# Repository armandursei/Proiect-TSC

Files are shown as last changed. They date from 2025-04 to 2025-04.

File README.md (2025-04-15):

# OpenBook e-Reader 
EBook_1

## Bill of Materials (BOM)

| Nume | Componenta | Link Cumpărare | Datasheet |
|---|---|---|---|
| Condensator C0402 | CC0402MRX5R5BB106 | [Link](https://ro.mouser.com/ProductDetail/YAGEO/CC0402MRX5R5BB106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) | [Datasheet](https://ro.mouser.com/datasheet/2/447/upy_gphc_x5r_4v_to_50v-3461255.pdf) |
| C10_SUPERCAP | CPH3225A | [Link](https://www.digikey.ro/en/products/detail/seiko-instruments/CPH3225A/8692444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) | [Datasheet](https://mm.digikey.com/Volume0/opasdata/d220001/medias/docus/6537/rev05-CPHCPM.pdf) |
| C3 TANT  | F910J107MBAAJ6 | [Link](https://ro.mouser.com/ProductDetail/KYOCERA-AVX/F910J107MBAAJ6?qs=PqoDHHvF649LraCA%2FjeGXg%3D%3D) | [Datasheet](https://ro.mouser.com/datasheet/2/40/F91_AJ6-3162641.pdf) |
| CHG_LED  | KP-1608SURCK | [Link](https://www.arrow.com/en/products/kp-1608surck/kingbright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) | [Datasheet](https://www.snapeda.com/parts/KP-1608SURCK/Kingbright/datasheet/) |
| D1 | USBLC6-2SC6Y | [Link](https://www.digikey.ro/en/products/detail/stmicroelectronics/USBLC6-2SC6Y/2756523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) | [Datasheet](https://componentsearchengine.com/Datasheets/1/USBLC6-2SC6Y.pdf) |
| D2, D7 | SD0805S020S1R0 | [Link](https://www.verical.com/pd/kyocera-avx-components-corporation-rectifier-SD0805S020S1R0-10867582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) | [Datasheet](https://www.digikey.ph/en/products/detail/kyocera-avx/SD0805S020S1R0/3749517) |
| D3, D4,D5 | MBR0530 | [Link](https://www.digikey.ro/en/products/detail/smc-diode-solutions/MBR0530/16692306) | [Datasheet](https://www.onsemi.com/pdf/datasheet/mbr0530-d.pdf) |
| D6, D8, D9, D10, D11, D12  | PGB1010603MR | [Link](https://www.digikey.ro/en/products/detail/littelfuse-inc/PGB1010603MR/715755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) | [Datasheet](https://www.snapeda.com/parts/PGB1010603MR/Littelfuse%20Inc./datasheet/) |
| IC1  | BD5229G-TR | [Link](https://www.digikey.ro/en/products/detail/rohm-semiconductor/BD5229G-TR/3663792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) | [Datasheet](https://datasheet.datasheetarchive.com/originals/distributors/Datasheets_SAMA/f2b9741ef86007909f138d561a359946.pdf) |
| IC4  | XC6220A331MR-G | [Link](https://www.digikey.ro/en/products/detail/torex-semiconductor-ltd/XC6220A331MR-G/21780806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) | [Datasheet](https://product.torexsemi.com/system/files/series/xc6220.pdf) |
| J1  | FH34SRJ-24S-0.5SH(99) | [Link](https://www.digikey.ro/en/products/detail/hirose-electric-co-ltd/FH34SRJ-24S-0.5SH(99)/5156248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) | [Datasheet](https://www.hirose.com/en/product/document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) |
| J2  | USB4110-GF-A | [Link](https://ro.mouser.com/ProductDetail/GCT/USB4110-GF-A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.) | [Datasheet](https://gct.co/files/drawings/usb4110.pdf) |
| J3 | SM04B-SRSS-TB | [Link](https://ro.mouser.com/ProductDetail/JST-Commercial/SM04B-SRSS-TBLFSN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) | [Datasheet](https://www.snapeda.com/parts/SM04B-SRSS-TB(LF)(SN)/JST%20Sales/datasheet/) |
| J4 | 112A-TAAR-R03 ATTEND | [Link](https://www.digikey.ro/en/products/detail/attend-technology/112A-TAAR-R03/17633923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) | [Datasheet](https://www.attend.com.tw/data/download/file/112A-TAAR-R03.pdf) |
| L1  | 744043680 | [Link](https://www.chip1stop.com/USA/en/products/Wurth-Electronics/744043680/WURT*0001522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) | [Datasheet](https://download.siliconexpert.com/pdfs/2018/1/3/16/30/56/604/weg_/manual/401950550574837744043680.pdf) |
| PFMF.050.1 | B72520T0350K062 | [Link](https://ro.mouser.com/ProductDetail/EPCOS-TDK/B72520T0350K062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) | [Datasheet](https://datasheet.datasheetarchive.com/originals/distributors/Datasheets_SAMA/81dc50a8c35dfdf39bcf4cbe36cdf37d.pdf) |
| Q1, Q2 | DMG2305UX-7 | [Link](https://www.digikey.ro/en/products/detail/diodes-incorporated/DMG2305UX-7/4340666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) | [Datasheet](https://www.diodes.com//assets/Datasheets/DMG2305UX.pdf) |
| Q3  | Si1308EDL-T1-GE3 | [Link](https://www.digikey.ro/ro/products/detail/vishay-siliconix/SI1308EDL-T1-GE3/4876435) | [Datasheet](https://componentsearchengine.com/Datasheets/1/SI1308EDL-T1-GE3.pdf) |
| Rezistenta 0402 | RC0402FR-07100KL | [Link](https://ro.mouser.com/ProductDetail/YAGEO/RC0402FR-07100KL?qs=mnq%2FyloZIXzTlUn7JAHSWg%3D%3D) | [Datasheet](https://www.yageo.com/upload/media/product/products/datasheet/rchip/PYu-RC_Group_51_RoHS_L_12.pdf) |
| RESET_BUTTON, CHANGE_BUTTON, BOOT_BUTTON | EVQPUJ02K | [Link](https://ro.mouser.com/ProductDetail/Panasonic/EVQ-PUJ02K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) | [Datasheet](https://www.alldatasheet.com/datasheet-pdf/view/537835/PANASONIC/EVQPUJ02K.html) |
| SENSOR2  | BME680 | [Link](https://www.digikey.ro/en/products/detail/bosch-sensortec/BME680/7401317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) | [Datasheet](https://www.snapeda.com/parts/BME680/Bosch%20Sensortec/datasheet/) |
| SJ1 | Solid Jumpers | [Link](https://ro.mouser.com/ProductDetail/Keystone-Electronics/5104?qs=SKxV22VtNmeKXYob26ai6Q%3D%3D) | [Datasheet](https://www.digikey.ro/en/htmldatasheets/production/1809569/0/0/1/jumpers) |
| U1 | W25Q512JVEIQ | [Link](https://www.digikey.ro/en/products/detail/winbond-electronics/W25Q512JVEIQ/10244706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) | [Datasheet](https://www.snapeda.com/parts/W25Q512JVEIQ/Winbond%20Electronics/datasheet/) |
| U2  | ESP32-C6-WROOM-1-N8 | [Link](https://www.digikey.ro/en/products/detail/espressif-systems/ESP32-C6-WROOM-1-N8/17728866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) | [Datasheet](https://www.snapeda.com/parts/ESP32-C6-WROOM-1-N8/Espressif%20Systems/datasheet/) |
| U3  | DS3231SN# | [Link](https://www.digikey.ro/en/products/detail/analog-devices-inc-maxim-integrated/DS3231SN/1197576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) | [Datasheet](https://www.snapeda.com/parts/DS3231SN%23/Analog%20Devices/datasheet/) |
| U4  | MAX17048G+T10 | [Link](https://www.digikey.ro/en/products/detail/analog-devices-inc-maxim-integrated/MAX17048G-T10/3758921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) | [Datasheet](https://www.snapeda.com/parts/MAX17048G+T10/Analog%20Devices/datasheet/) |
| U5  | MCP73831 | [Link](https://ro.mouser.com/ProductDetail/Microchip-Technology/MCP73831T-2ACI-OT?qs=yUQqVecv4qvbBQBGbHx0Mw%3D%3D) | [Datasheet](https://datasheet.datasheetarchive.com/originals/distributors/Datasheets-DGA15/727147.pdf) |

## Diagrama Bloc
svgviewer-png-output

# Descriere Hardware
PCB_2

## Introducere
OpenBook este un dispozitiv e-book reader open-source și accesibil, conceput pentru a oferi o experiență de lectură eficientă și cu consum redus de energie. Proiectarea hardware urmărește obținerea unei soluții robuste, cu interconectări curate și o bună compatibilitate electromagnetică.
Dispozitivul este construit în jurul microcontroller-ului ESP32-C6, care oferă conectivitate Wi-Fi și Bluetooth Low Energy (BLE), o putere de procesare eficientă și suport extins pentru periferice.
## Microcontroller: ESP32-C6-WROOM-1-N8
- Procesor: RISC-V 32-bit, frecvență până la 160 MHz
- Memorie: 8MB Flash integrată + memorie externă SPI NOR Flash de 64 MB (W25Q512JVEIQ) pentru stocarea conținutului cărților electronice
- Interfețe utilizate:
  - SPI: conectat la display-ul e-paper și la memoria externă NOR Flash
  - I2C: pentru senzori externi (ex. senzor de mediu BME688) și RTC (DS3231SN)
  - UART: disponibil pentru debugging
  - GPIO: folosit pentru butoane de control, reset, și alte semnale de comandă pentru periferice
- Antena: Amplasată corect, conform cerințelor, spre exteriorul PCB-ului, cu decupare sub antenă pentru evitarea interferențelor.
## Module și componente principale
### Display e-Paper

Interfață: SPI

Control semnale: EPD_CS, EPD_RST, EPD_DC, EPD_BUSY

Display consum redus de energie, perfect pentru citire pe durată lungă.

### Memorie Externă

Model: W25Q512JVEIQ, 512Mbit NOR Flash

Interfață: SPI

Utilizare: stocare cărți electronice, fonturi, imagini etc.

### Senzor de mediu: BME688

Funcții: măsurare temperatură, presiune, umiditate și compuși organici volatili (VOC)

Interfață: I2C

Consum: extrem de redus.

### Modul RTC (Real Time Clock) — DS3231SN

Funcție: menține ora exactă, chiar și în absența alimentării principale

Interfață: I2C

Include funcționalitate de alarmă și ieșire SQW/INT.

### Baterie și circuit de încărcare

Controler încărcare: MCP73831

Indicator stare: LED 'CHG_LED'

Conector: USB-C pentru încărcare rapidă

Protecție la supratensiune și ESD.

### Sursă de alimentare și reglare tensiune

Regulator LDO: XC6220A331MR-G, 3.3V stabilizat

Condensatori de decuplare de 100nF

Trasee de alimentare rutate cu lățime de 0.3mm.

### Port de extindere Qwiic / Stemma QT

Pentru conectarea rapidă a senzorilor sau modulelor suplimentare prin I2C.

### Test pads marcate clar

Semnalele importante sunt disponibile pentru debugging și testare.

## Conectivitate și comunicare

| Componentă | Interfață cu MCU | Linii semnal |
|---|---|---|
| Display e-paper | SPI | MOSI, MISO, SCK, CS, DC, BUSY, RST |
| Memorie externă Flash | SPI | MOSI, MISO, SCK, CS |
| RTC | I2C | SDA, SCL |
| Senzor BME688 | I2C | SDA, SCL |
| Port extensie Qwiic | I2C | SDA, SCL |
| Charging Controller | USB | VBUS, GND, STAT LED |

## Management consum de energie
- Display-ul e-paper consumă energie doar la schimbarea imaginii.
- ESP32 poate intra în moduri de deep sleep pentru maximizarea autonomiei.
- RTC funcționează cu consum ultra scăzut și poate trezi MCU la intervale prestabilite.
- Alimentare stabilizată la 3.3V prin LDO cu ripple redus.
- Condensatori de filtrare atent poziționați pentru minimizarea zgomotului.
### Estimare consum tipic:

Stare dispozitiv	                Consum estimativ

Active Wi-Fi + e-paper update	    ~180-250 mA

Standby cu RTC activ	            ~10-20 µA

Deep Sleep	                      ~2.5 µA

## Considerații suplimentare
- PCB-ul este proiectat pe două straturi, cu plan de masă solid și via stitching pentru performanță EMC îmbunătățită.
- Sub antena ESP32 PCB-ul este decupat pentru a reduce interferențele radio.
- Toate componentele sunt SMD, capsulă 0402, cu excepția celor specificate diferit în schematic.
- Componentele sunt amplasate exclusiv pe layer-ul TOP pentru o producție mai facilă.
# Pin Mapping ESP32-C6
# OpenBook e-Reader — Atribuire pini ESP32-C6

| Componentă | Pin ESP32-C6 | Funcție | Motivare alegere |
|---|---|---|---|
| Display e-paper (SPI) | IO4 (MOSI) | MOSI | Pin dedicat SPI, viteză mare pentru trimitere date la display |
| | IO5 (MISO) | MISO | Comunicare bidirecțională SPI |
| | IO6 (SCK) | Clock SPI | Sincronizare transfer date |
| | IO7 | Chip Select | Activare selectivă display |
| | IO8 | Data/Command (DC)  | Comutare între date și comenzi |
| | IO9 | Reset Display (RST)| Reset hardware display |
| | IO10 | Busy Pin | Verificare stare display pentru sincronizare fără blocare |
| Memorie externă Flash (SPI)  | IO4 (MOSI) | MOSI | Partajare magistrală SPI cu display |
| | IO5 (MISO) | MISO | Partajare magistrală SPI cu display |
| | IO6 (SCK) | Clock SPI | Partajare magistrală SPI cu display |
| | IO11 | Chip Select Flash  | Separare comunicație SPI față de display |
| RTC DS3231SN (I2C) | IO18 | SDA | Linie de date I2C, partajată cu senzor BME688 |
| | IO19 | SCL | Clock I2C, partajat cu senzor BME688 |
| Senzor BME688 (I2C) | IO18 | SDA | Linie de date partajată cu RTC |
| | IO19 | SCL | Clock partajat cu RTC |
| Buton de Reset | EN | Reset | Pin nativ ESP32 pentru reset hardware |
| Buton de Boot/IO | IO0 | Boot | Intrare pentru modul de boot/flash firmware |
| Charging Status (LED) | IO13 | GPIO Output | Semnalizare vizuală stare încărcare |
| Test pad-uri Debug UART | IO16 | TXD0 | Linie de transmisie UART pentru debug |
| | IO17 | RXD0 | Linie de recepție UART pentru debug |

## Explicații detaliate
### Display e-paper

Am ales să folosim SPI, deoarece e-paper are nevoie de transferuri rapide de date pentru actualizări eficiente ale ecranului.

Pinul IO4 (MOSI) și IO6 (SCK) sunt convențional buni pentru SPI, oferind viteze mari de transfer.

Pinul de Chip Select (IO7) separă comunicarea față de memoria Flash externă, iar IO8 (DC) controlează modul de funcționare (date/comenzi).

IO9 (RST) asigură reset hardware pentru inițializarea display-ului.

IO10 (BUSY) permite MCU-ului să verifice dacă ecranul e-paper este ocupat, evitând astfel blocajele.

### Memorie externă Flash

Partajăm magistrala SPI cu display-ul pentru eficiență (reducere număr pini).

Am folosit Chip Select separat (IO11) pentru Flash, astfel încât ESP32 să poată comuta între display 
și memorie externă după nevoie.

### RTC și Senzor BME688

Folosim I2C comun pentru ambele componente pentru simplitate și economie de pini.

Linia SDA (IO18) și SCL (IO19) sunt partajate fără probleme, întrucât atât RTC-ul cât și senzorul BME688 au adrese I2C diferite.

### Circuit de încărcare baterie

Indicatorul de stare (STAT) este conectat la IO13, ca să putem afișa cu LED starea de încărcare.

### Butoane hardware

Butonul de reset este legat la EN, care este pinul nativ de reset al ESP32.

Butonul de boot este pe IO0, conform recomandărilor ESP32 pentru intrarea în modul de programare (flash firmware).

### Test pad-uri Debug

UART hardware ESP32-C6:
- TXD0 = IO16
- RXD0 = IO17

Astfel, putem face debugging rapid prin UART fără să ocupăm pini suplimentari pentru comunicație.

### Considerații adiționale

Toți pinii critici de alimentare sunt decuplați cu condensatori de 100nF montați aproape de pini.

Pinii folosiți pentru comunicații de mare viteză (SPI) sunt poziționați cu trasee scurte pentru a evita interferențele și cross-talk-ul.

Pinii de alimentare și date respectă specificațiile de lățime traseu: alimentare 0.3mm, date 0.15mm minim.

## Pașii de implementare, probleme întâmpinate și decizii de proiectare
### 1. Analiza cerințelor și planificarea
Am pornit de la specificațiile oferite de Arhitectul de Sistem, incluzând cerințele legate de rutare, dimensiuni, modul de amplasare a componentelor și normele EMC.
Am stabilit următoarele priorități:
- Miniaturizarea PCB-ului fără a compromite performanța RF.
- Asigurarea unei alimentări stabile și curate pentru toate modulele.
- Design modular, cu posibilitate de extensie prin conectorul Qwiic / Stemma QT.
### 2. Crearea schematicului electric
- Tool utilizat: Fusion
- Am inclus toate modulele cerute: ESP32-C6, RTC, senzor BME688, controller încărcare baterie, memorie externă NOR Flash, e-paper.
- Am adăugat protecție ESD pentru liniile sensibile (USB, SPI).
- Toate alimentările sunt filtrate cu condensatori de decuplare de 100nF, plasați cât mai aproape de pinii circuitelor integrate.
### 3. Layout PCB
Tool utilizat: Fusion

Amplasarea componentelor s-a realizat exclusiv pe layer-ul TOP, conform cerinței.

Am acordat o atenție deosebită următoarelor aspecte:
- Antena ESP32: amplasată la marginea plăcii, cu decupare sub antenă pentru a evita interferențele.
- Planuri de masă: am utilizat două straturi de plan de masă și aplicat via stitching intensiv, mai ales în zona ESP32 pentru integritate semnal și reducere EMI.
- Lățimi trasee: am respectat cerințele — alimentare 0.3mm, date min. 0.15mm.
- Test pad-uri: marcate clar pe silkscreen pentru facilitarea testării în faza de prototip și producție.

## Probleme întâmpinate:

- Conflict spațial în jurul modulului ESP32

- Modulul ESP32-C6 și componentele de alimentare și filtrare RF necesitau plasare compactă.

  Soluție: am rearanjat componentele pentru a evita utilizarea de vias pe traseele de alimentare critice, păstrând totodată trasee scurte pentru semnalele de mare viteză.

- Overlap parțial plan de masă și zona antenei

- Am detectat inițial o intersecție accidentală a planului de masă cu zona de sub antena ESP32.

  Decizie: am ajustat conturul planului de masă pentru a menține zona sub antenă complet liberă de cupru și trasee, astfel încât să reducem interferențele RF.

- Erori de clearance / distanță minimă între trasee

- În anumite zone dense (ex: header-ul display-ului e-paper), am acceptat un clearance minim redus, întrucât fabricația modernă permite aceste toleranțe fără probleme.

  Am verificat designul cu DRC (Design Rule Check) pentru a ne asigura că rămâne în limitele permise de procesul de fabricație.

- Trasee lungi SPI către e-paper

- Fiind vorba de un semnal de mare viteză, am minimizat lungimea traseelor SPI prin plasarea controlerului e-paper cât mai aproape de ESP32, fără a compromite layout-ul general.

### 4. Verificare design (Design Review)
Am verificat manual toate traseele critice de alimentare și comunicații.
Am verificat DRC și ERC (Electrical Rule Check) cu tool-ul primit.
### 5. Pregătire pentru producție
Am generat fișierele Gerber și BOM (Bill of Materials).
### 6. Integrare 3D și Ansamblu final
- Model 3D pentru display și baterie:
  Am creat modele 3D detaliate pentru display-ul e-paper și pentru bateria Li-Po, pentru a verifica potrivirea componentelor în ansamblu.

- Integrare în carcasa existentă: Carcasa dispozitivului a fost preexistentă, însă am verificat alinierea perfectă a PCB-ului, ecranului și conectorilor în cadrul carcasei.
Am ajustat poziționarea componentelor astfel încât:
  - Ecranul să fie corect centrat și bine susținut mecanic.
  - Accesul la portul USB-C pentru încărcare să fie facil.
  - Zonele pentru antenă să fie libere de obstacole mecanice, pentru optimizarea performanței RF.

- Ansamblul complet:
  Am realizat ansamblul final al dispozitivului, verificând:
  - Compatibilitatea tuturor componentelor între ele.
  - Posibilitatea de asamblare eficientă în producție de masă.
  - Rigiditatea mecanică și siguranța fixării componentelor critice.

- Verificare clearance și coliziuni:
  Am utilizat funcționalitățile software de verificare pentru a elimina orice potențiale coliziuni între PCB, display și carcasă.

Decizie:
Integrarea 3D ne-a ajutat să anticipăm și să prevenim probleme mecanice înainte de prototipare fizică, economisind timp și resurse.
## Observații suplimentare pentru
### 1. Design log și proces iterativ
Am menținut un jurnal de design pe parcursul întregului proiect pentru a urmări deciziile și iterațiile importante:
- Inițial: amplasare funcțională, fără optimizări mecanice.
- Revizia 1: optimizare rutare alimentare pentru a evita vias pe liniile de putere.
- Revizia 2: îmbunătățire layout antenă ESP32 conform cerințelor RF, eliminare completă cupru sub antenă.
- Revizia 3: verificări de clearance și marcaje test pad-uri adăugate.
- Final: integrare 3D și verificare ansamblu complet.

Fiecare modificare a fost documentată și validată cu peer-review înainte de trecerea la următoarea etapă, pentru a asigura trasabilitatea deciziilor tehnice.
### 2. Așezarea componentelor în carcasă
Am tratat cu maximă atenție integrarea PCB-ului în carcasă, pentru a preveni probleme de asamblare:
- Ecran e-paper: Poziționat central, cu suport mecanic prin carcasă, astfel încât să nu existe flexare excesivă a PCB-ului în timpul montajului.
- Conector USB-C: Verificat poziționarea precisă față de decupajul carcasei pentru a asigura conectivitate ușoară și fără tensiune mecanică asupra PCB-ului.
- Bateria: Amplasată astfel încât să fie bine susținută mecanic de carcasă și conectată fără forțări la conectorul de alimentare.
- Test pad-uri și acces pentru testare: Test pad-urile sunt plasate în zone accesibile chiar și după asamblarea mecanică parțială, pentru testare de producție și depanare rapidă.
### 3. Considerații pentru fabricație și asamblare
- Montaj exclusiv pe TOP layer — simplifică semnificativ procesul de asamblare SMT.
- Testabilitate: Am prevăzut acces facil la semnalele critice prin test pad-uri, inclusiv alimentare, date SPI/I2C și UART debug.
- Marcare clară a componentelor: Silkscreen detaliat pentru identificarea ușoară a componentelor în timpul asamblării și depanării.
- Gerber Files și BOM pregătite complet pentru producție.
### 4. Recomandări pentru viitor
- Se poate lua în considerare utilizarea unor conectori interni suplimentari pentru extensii hardware (de exemplu: card reader extern sau interfață audio).
- O viitoare iterație poate integra și un sistem de ancorare mecanică mai robust pentru baterie.
- Posibilitate de optimizare suplimentară a layout-ului pentru EMC, prin adăugarea de ferite pe liniile critice de alimentare.
## Concluzii
Prin acest proces, am obținut un design robust, pregătit pentru producție de masă, care respectă toate cerințele de design impuse:
- Optimizare RF pentru modulul ESP32.
- Fiabilitate electrică prin alimentare stabilizată și filtrată.
- Extensibilitate prin conectorul I2C dedicat.

Deciziile noastre de layout și compromisurile (acceptarea unor clearance minime, optimizarea pentru fabricație) au fost deliberate și validate atât prin analiza manuală, cât și prin verificări automate.
Pe lângă validarea electrică și de fabricație, proiectul a fost validat și la nivel mecanic prin integrarea completă în ansamblul 3D al dispozitivului.
Acest lucru asigură nu doar funcționarea corectă a circuitului, ci și faptul că produsul final va avea un aspect profesional și va fi ușor de asamblat în producția de masă.

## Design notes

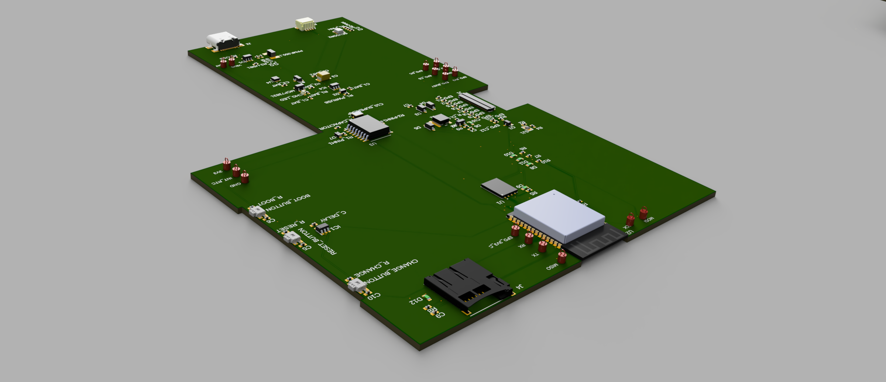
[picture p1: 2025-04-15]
Images/PCB_3.png

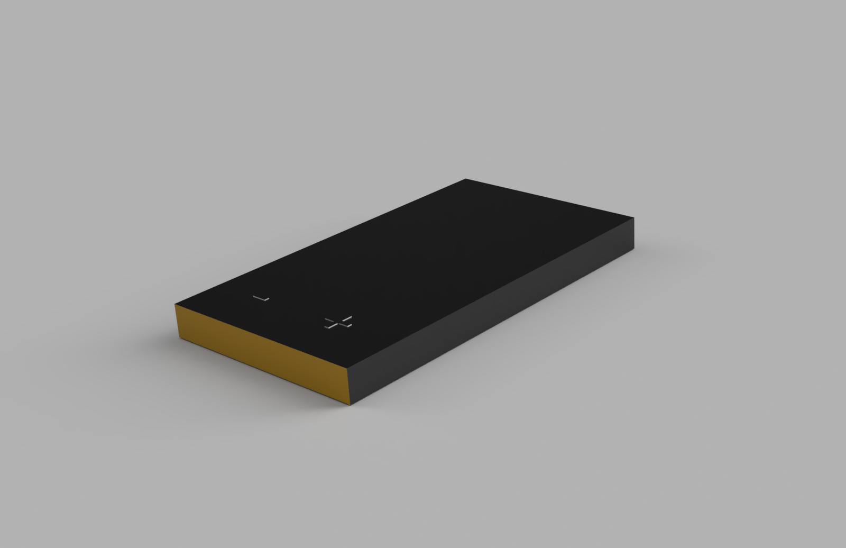
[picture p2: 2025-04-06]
Images/Battery.PNG

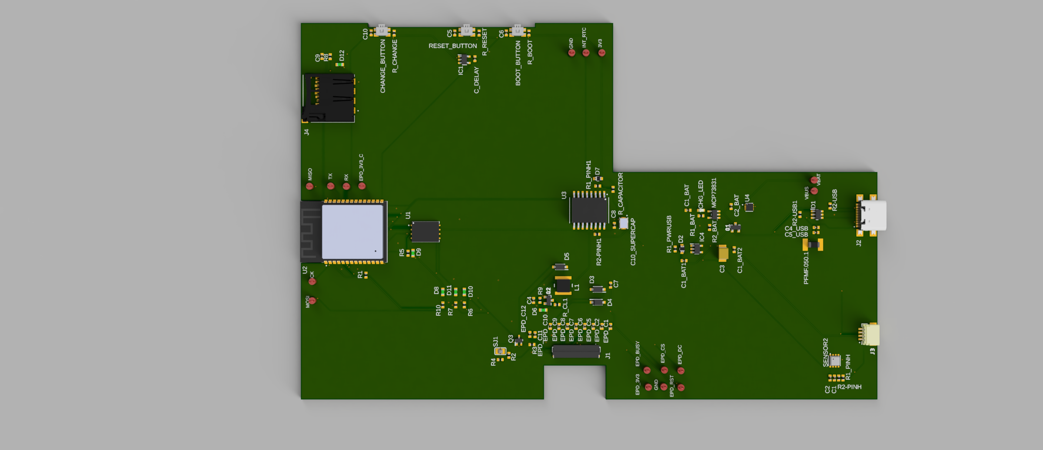
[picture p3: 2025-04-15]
Images/PCB_1.png

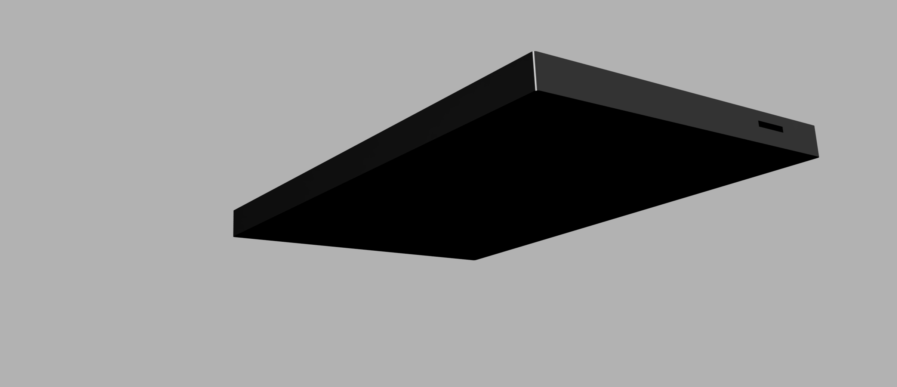
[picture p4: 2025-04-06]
Images/EBook_2.PNG

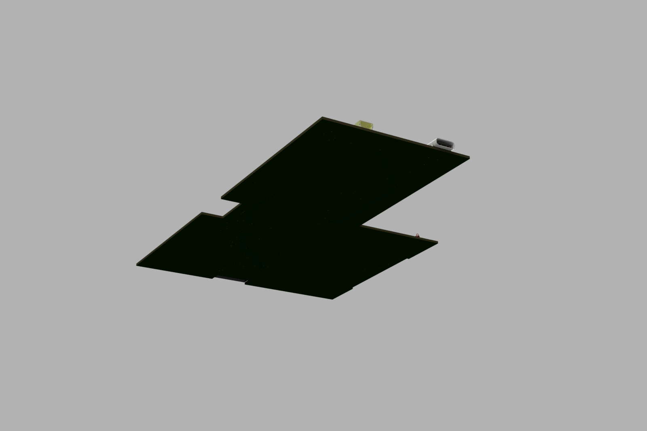
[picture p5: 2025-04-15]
Images/PCB_5.PNG

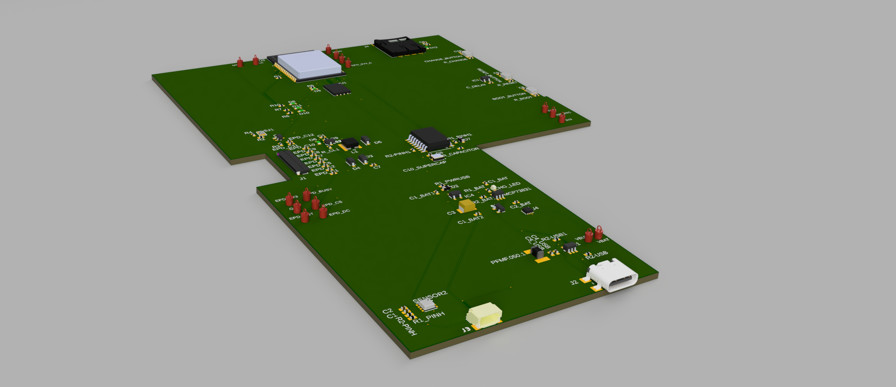
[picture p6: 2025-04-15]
Images/PCB_2.png

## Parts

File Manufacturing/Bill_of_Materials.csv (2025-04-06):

Qty | Value | Device | Package | Parts | Description | ARROW_PART_NUMBER | ARROW_PRICE-STOCK | AVAILABILITY | CENTROID_NOT_SPECIFIED | CHECK_PRICES | COPYRIGHT | DATASHEET | DESCRIPTION | DIGIKEY_DESCRIPTION | DIGIKEY_PART_NUMBER | HEIGHT | LEAD_FREE | MANUFACTURER_NAME | MANUFACTURER_PART_NUMBER | MF | MFR_NAME | MOUSER_PART_NUMBER | MOUSER_PRICE-STOCK | MOUSER_TESTING_PART_NUMBER | MOUSER_TESTING_PRICE-STOCK | MP | MPN | PACKAGE | POPULARITY | PREFIX | PRICE | PROD_ID | PURCHASE-URL | ROHS | SNAPEDA_LINK | SPICEPREFIX | TEMPERATURE_RANGE_HIGH | TEMPERATURE_RANGE_LOW | VALUE
1 |  | ADAFRUIT_LEDCHIP-LED0603 | ADAFRUIT_CHIP-LED0603 | CHG_LED | LED
1 |  | SJ | SJ | SJ1 | SMD solder JUMPER |  |  |  |  |  |  |  |  |  |  |  |  |  |  |  |  |  |  |  |  |  |  |  | 3
1 | 0.1uF/50V | ESP32_WROVER_EAGLE-LTSPICE_CC0402 | ESP32_WROVER_EAGLE-LTSPICE_C0402 | EPD_C5 | CAPACITOR, European symbol
1 | 0.47 | ESP32_WROVER_EAGLE-LTSPICE_RR0402 | ESP32_WROVER_EAGLE-LTSPICE_R0402 | R3 | RESISTOR, European symbol
1 | 100K | ESP32_WROVER_EAGLE-LTSPICE_RR0402 | ESP32_WROVER_EAGLE-LTSPICE_R0402 | R1_PWRUSB | RESISTOR, European symbol
8 | 100nF | ESP32_WROVER_EAGLE-LTSPICE_CC0402 | ESP32_WROVER_EAGLE-LTSPICE_C0402 | C1, C2, C4_USB, C6, C8, C9, C10, C_DELAY | CAPACITOR, European symbol
1 | 100uF TANT | RCL_CPOL-EUCT3528 | RCL_CT3528 | C3 | POLARIZED CAPACITOR, European symbol |  |  |  |  |  |  |  |  |  |  |  |  |  |  |  |  |  |  |  |  |  |  |  | 0 |  |  |  |  |  |  | C
16 | 10K | ESP32_WROVER_EAGLE-LTSPICE_RR0402 | ESP32_WROVER_EAGLE-LTSPICE_R0402 | R1, R1_PINH, R1_PINH1, R2-PINH, R2-PINH1, R4, R5, R6, R7, R8, R9, R10, R_BOOT, R_CHANGE, R_CL1, R_RESET | RESISTOR, European symbol
1 | 10uF | ESP32_WROVER_EAGLE-LTSPICE_CC0402 | ESP32_WROVER_EAGLE-LTSPICE_C0402 | C7 | CAPACITOR, European symbol
1 | 112A-TAAR-R03_ATTEND | 112A-TAAR-R03_ATTEND | 112ATAARR03ATTEND | J4 | Micro SD Card Socket, Push-Push Type, Top Mount, SMT, H=1.83mm, 10u |  |  |  |  |  |  |  | Micro SD Card Socket | Push-Push Type | Top Mount | SMT | H=1.83mm | 10u |  |  | 1.9mm |  | ATTEND | 112A-TAAR-R03 ATTEND
1 | 15 | ESP32_WROVER_EAGLE-LTSPICE_RR0402 | ESP32_WROVER_EAGLE-LTSPICE_R0402 | R_CAPACITOR | RESISTOR, European symbol
1 | 1uF | ESP32_WROVER_EAGLE-LTSPICE_CC0402 | ESP32_WROVER_EAGLE-LTSPICE_C0402 | C5 | CAPACITOR, European symbol
9 | 1uF/50V | ESP32_WROVER_EAGLE-LTSPICE_CC0402 | ESP32_WROVER_EAGLE-LTSPICE_C0402 | EPD_C1, EPD_C2, EPD_C6, EPD_C7, EPD_C8, EPD_C9, EPD_C10, EPD_C11, EPD_C12 | CAPACITOR, European symbol
1 | 2.2 | ESP32_WROVER_EAGLE-LTSPICE_RR0402 | ESP32_WROVER_EAGLE-LTSPICE_R0402 | R2 | RESISTOR, European symbol
1 | 200 | ESP32_WROVER_EAGLE-LTSPICE_RR0402 | ESP32_WROVER_EAGLE-LTSPICE_R0402 | R1_BAT | RESISTOR, European symbol
2 | 20V/4.2A/52mΩ/1.4W | ESP32_WROVER_SPARKFUN-DISCRETESEMI_MOSFET_PCH-DMG2305UX-7 | ESP32_WROVER_SPARKFUN-DISCRETESEMI_SOT23-3 | Q1, Q2 | P-channel MOSFETs |  |  |  |  |  |  |  |  |  |  |  |  |  |  |  |  |  |  |  |  |  |  |  |  |  |  | TRAN-14388 |  |  |  |  |  |  | 20V/4.2A/52mΩ/1.4W
1 | 2K | ESP32_WROVER_EAGLE-LTSPICE_RR0402 | ESP32_WROVER_EAGLE-LTSPICE_R0402 | R2_BAT | RESISTOR, European symbol
5 | 4.7uF | ESP32_WROVER_EAGLE-LTSPICE_CC0402 | ESP32_WROVER_EAGLE-LTSPICE_C0402 | C1_BAT, C1_BAT1, C1_BAT2, C2_BAT, C5_USB | CAPACITOR, European symbol
1 | 4.7uF/25V | ESP32_WROVER_EAGLE-LTSPICE_CC0402 | ESP32_WROVER_EAGLE-LTSPICE_C0402 | C4 | CAPACITOR, European symbol
2 | 5k1 | ESP32_WROVER_EAGLE-LTSPICE_RR0402 | ESP32_WROVER_EAGLE-LTSPICE_R0402 | R2-USB, R2-USB1 | RESISTOR, European symbol
1 | 68uH | 744043680IND_4828-WE-TPC_WRE | IND_4828-WE-TPC_WRE | L1 |  |  |  |  |  |  | Copyright (C) 2024 Ultra Librarian. All rights reserved. |  |  |  |  |  |  |  | 744043680 |  | Wurth Electronics
1 | BD5229G-TR | BD5229G-TR | SOT95P280X125-5N | IC1 | Voltage Detector with Adjustable Delay Time: CMOS processes are utilized to develop high precision, low current consumption CMOS reset ICs that allow arbitrary setting of the delay time. The extensive lineup includes both Nch Open Drain and CMOS output types in a wide range of detection voltages (from 2.3V to 6.0V, in 0.1V steps), enabling selection of the ideal solution based on customer requirements. In addition, the entire series is of course both lead-free and RoHS-compliant. |  |  |  |  |  |  |  | Voltage Detector with Adjustable Delay Time: CMOS processes are utilized to develop high precision | low current consumption CMOS reset ICs that allow arbitrary setting of the delay time. The extensive lineup includes both Nch Open Drain and CMOS output types in a wide range of detection voltages (from 2.3V to 6.0V | in 0.1V steps) | enabling selection of the ideal solution based on customer requirements. In addition | the entire series is of course both lead-free and RoHS-compliant. |  |  | 1.25mm |  | ROHM Semiconductor | BD5229G-TR |  |  | 755-BD5229G-TR | https://www.mouser.co.uk/ProductDetail/ROHM-Semiconductor/BD5229G-TR?qs=4kLU8WoGk0vvnhrrYwdszw%3D%3D
1 | BME688 | ESP32_WROVER_BME680_BME680 | ESP32_WROVER_BME680_PSON80P300X300X100-8N | SENSOR2 | Integrated Environmental Unit |  |  | Unavailable |  |  |  |  | Integrated Environmental Unit |  |  |  |  |  |  | Bosch Sensortec |  |  |  |  |  | BME680 |  | LGA-8 Bosch Tools |  |  | None
3 | BUTTON_CUSYOMV1 | BUTTON_CUSYOMV1 | MYBUTTON | BOOT_BUTTON, CHANGE_BUTTON, RESET_BUTTON
1 | CPH3225A | CPH3225A | CAPCP3225X100N | C10_SUPERCAP | Cap 0.011F 3.3V 1210 Flat Check availability |  |  | Not in stock |  | https://www.snapeda.com/parts/CPH3225A/Seiko+Instruments/view-part/?ref=eda |  |  | 11 mF (EDLC) Supercapacitor 3.3 V 1210 (3225 Metric) - - |  |  |  |  |  |  | Seiko Instruments |  |  |  |  |  | CPH3225A |  | 1210 Seiko |  |  | None |  | https://www.snapeda.com/api/url_track_click_mouser/?unipart_id=562593&manufacturer=Seiko Instruments&part_name=CPH3225A&search_term=None |  | https://www.snapeda.com/parts/CPH3225A/Seiko+Instruments/view-part/?ref=snap
1 | DS3231SN# | DS3231SN# | SOIC127P1032X265-16N | U3 | Real Time Clock Serial 16-Pin SOIC W T/R Check availability |  |  | In Stock |  | https://www.snapeda.com/parts/DS3231SN%23/Analog+Devices/view-part/?ref=eda |  |  | Extremely Accurate I²C-Integrated RTC/TCXO/Crystal |  |  |  |  |  |  | Analog Devices |  |  |  |  |  | DS3231SN# |  | SOIC-16 Maxim |  |  | None |  | https://www.snapeda.com/api/url_track_click_mouser/?unipart_id=99048&manufacturer=Analog Devices&part_name=DS3231SN#&search_term=None |  | https://www.snapeda.com/parts/DS3231SN%23/Analog+Devices/view-part/?ref=snap
1 | ESP32-C6-WROOM-1-N8 | ESP32-C6-WROOM-1-N8 | XCVR_ESP32-C6-WROOM-1-N8 | U2 | Check availability |  |  | In Stock |  | https://www.snapeda.com/parts/ESP32-C6-WROOM-1-N8/Espressif+Systems/view-part/?ref=eda |  |  | Multiprotocol Modules ESP32-C6 module | Wi-Fi 6 in 2.4 GHz band | Bluetooth 5 | Zigbee 3.0 and Thread. ESP34-WROOM Compatible - ENGINEERING SAMPLE |  |  |  |  |  |  | Espressif Systems |  |  |  |  |  | ESP32-C6-WROOM-1-N8 |  | None |  |  | None |  |  |  | https://www.snapeda.com/parts/ESP32-C6-WROOM-1-N8/Espressif+Systems/view-part/?ref=snap
1 | ESP32C6_VARISTORCN1812 | ESP32C6_VARISTORCN1812 | ESP32C6_VARISTOR_CT/CN1812 | PFMF.050.1 | VARISTOR |  |  |  |  |  |  |  |  |  |  |  |  |  |  |  |  |  |  |  |  |  |  |  | 0
1 | ESP32_WROVER_SPARKFUN-IC-POWER_MCP73831 | ESP32_WROVER_SPARKFUN-IC-POWER_MCP73831 | ESP32_WROVER_SPARKFUN-IC-POWER_SOT23-5 | MCP73831 | MCP73831T Li-Ion, Li-Pol Controller |  |  |  |  |  |  |  |  |  |  |  |  |  |  |  |  |  |  |  |  |  |  |  |  |  |  | IC-09995
1 | FH34SRJ-24S-0.5SH_99_ | FH34SRJ-24S-0.5SH_99_ | FH34SRJ24S05SH99 | J1 | (0.50mm) Surface Mount, Right Angle |  |  |  |  |  |  |  | 24 Position FFC | FPC Connector Contacts | (0.50mm) Surface Mount | Right Angle |  |  | 1.1mm |  | Hirose | FH34SRJ-24S-0.5SH(99) |  |  | 798-FH34SRJ24S05SH99 | https://www.mouser.co.uk/ProductDetail/Hirose-Connector/FH34SRJ-24S-0.5SH99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
1 | MAX17048G+T10 | MAX17048G+T10 | SON50P200X200X80-9N | U4 | Check availability |  |  | In Stock |  | https://www.snapeda.com/parts/MAX17048G+T10/Analog+Devices/view-part/?ref=eda |  |  | 3µA 1-Cell/2-Cell Fuel Gauge with ModelGauge |  |  |  |  |  |  | Analog Devices |  |  |  |  |  | MAX17048G+T10 |  | TDFN-8 Maxim |  |  | None |  | https://www.snapeda.com/api/url_track_click_mouser/?unipart_id=329239&manufacturer=Analog Devices&part_name=MAX17048G+T10&search_term=None |  | https://www.snapeda.com/parts/MAX17048G+T10/Analog+Devices/view-part/?ref=snap
3 | MBR0530 | MBR0530 | SOD3716X135N | D3, D4, D5 | ON SEMICONDUCTOR - MBR0530 - DIODE, SCHOTTKY, 0.5A, 30V, SOD-123
6 | PGB1010603MR | PGB1010603MR | DIOC1608X36N | D6, D8, D9, D10, D11, D12 | Check availability
1 | QWIIC_RIGHT_ANGLE | QWIIC_CONNECTORJS-1MM | JST04_1MM_RA | J3 | SparkFun I2C Standard Qwiic Connector |  |  |  |  |  |  |  |  |  |  |  |  |  |  |  |  |  |  |  |  |  |  |  |  |  |  | CONN-13694 |  |  |  |  |  |  | QWIIC_RIGHT_ANGLE
1 | SAMACSYS_PARTS_USB4110-GF-A | SAMACSYS_PARTS_USB4110-GF-A | SAMACSYS_PARTS_USB4110GFA | J2 | CONN USB 2.0 TYPE-C R/A SMT |  |  |  |  |  |  |  | CONN USB 2.0 TYPE-C R/A SMT |  |  | 3.26mm |  | GCT (GLOBAL CONNECTOR TECHNOLOGY) | USB4110-GF-A |  |  | 640-USB4110-GF-A | https://www.mouser.co.uk/ProductDetail/GCT/USB4110-GF-A?qs=KUoIvG%2F9IlYiZvIXQjyJeA%3D%3D
2 | SD0805S020S1R0 | ESP32_WROVER_AVX---SD0805S020S1R0_AVX_SD0805S020S1R0_0_0AVX_SD0805S020S1R0_0_0 | ESP32_WROVER_AVX---SD0805S020S1R0_AVX_SD0805S020S1R0_0 | D2, D7 | Schottky Barrier Rectifier Diode |  |  |  | No |  |  | http://datasheets.avx.com/schottky.pdf |  | DIODE SCHOTTKY 20V 1A 0805 | 478-7800-1-ND |  | yes |  |  | AVX |  | 581-SD0805S020S1R0 |  |  |  |  |  | 0805 (2012 metric) |  | D |  |  |  | yes |  |  | +125°C | -55°C
1 | SI1308EDL-T1-GE3 | SI1308EDL-T1-GE3 | SOT65P210X110-3N | Q3 | MOSFET N-Ch 30V 1.5A TrenchFET SC70 Vishay Si1308EDL-T1-GE3 N-channel MOSFET Transistor, 1.5 A, 30 V, 3-Pin SC-70 |  |  | In Stock |  | https://www.snapeda.com/parts/SI1308EDL-T1-GE3/Vishay+Siliconix/view-part/?ref=eda |  |  | Si1308EDL-T1-GE3 N-channel MOSFET Transistor | 1.5 A | 30 V | 3-Pin SC-70 | Siliconix / Vishay SI1308EDL-T1-GE3 |  |  |  |  |  |  | Vishay Siliconix |  |  |  |  |  | SI1308EDL-T1-GE3 |  | SOT-323 Vishay Semiconductor |  |  | None |  | https://www.snapeda.com/api/url_track_click_mouser/?unipart_id=274603&manufacturer=Vishay Siliconix&part_name=SI1308EDL-T1-GE3&search_term=None |  | https://www.snapeda.com/parts/SI1308EDL-T1-GE3/Vishay+Siliconix/view-part/?ref=snap
17 | TPTP20R | TPTP20R | TP20R | TP1, TP2, TP3, TP4, TP5, TP6, TP7, TP8, TP9, TP10, TP11, TP12, TP13, TP14, TP15, TP16, TP17 | Test pad
1 | USBLC6-2SC6Y | USBLC6-2SC6Y | SOT95P280X145-6N | D1 | Low Cap. ESD Protection Auto SOT-23-6 STMicroelectronics USBLC6-2SC6Y, Dual Uni-Directional TVS Diode Array, 6-Pin SOT-23 |  |  | In Stock |  | https://www.snapeda.com/parts/USBLC6-2SC6Y/STMicroelectronics/view-part/?ref=eda |  |  | 17V Clamp 5A (8/20µs) Ipp Tvs Diode Surface Mount SOT-23-6 |  |  |  |  |  |  | STMicroelectronics |  |  |  |  |  | USBLC6-2SC6Y |  | SOT-23-6 STMicroelectronics |  |  | None |  |  |  | https://www.snapeda.com/parts/USBLC6-2SC6Y/STMicroelectronics/view-part/?ref=snap
1 | W25Q512JVEIQ | W25Q512JVEIQ | SON127P600X800X80-9N | U1 | Check availability |  |  | In Stock |  | https://www.snapeda.com/parts/W25Q512JVEIQ/Winbond+Electronics/view-part/?ref=eda |  |  | FLASH - NOR Memory IC 512Mb (64M x 8) SPI - Quad I/O 133 MHz 8-WSON (8x6) |  |  |  |  |  |  | Winbond Electronics |  |  |  |  |  | W25Q512JVEIQ |  | Package |  |  | None |  |  |  | https://www.snapeda.com/parts/W25Q512JVEIQ/Winbond+Electronics/view-part/?ref=snap
1 | XC6220A331MR-G | XC6220A331MR-G | SOT95P280X120-5N | IC4 | LDO Voltage Regulators |  |  |  |  |  |  |  | LDO Voltage Regulators |  |  | 1.2mm |  | Torex | XC6220A331MR-G |  |  | 865-XC6220A331MR-G | https://www.mouser.co.uk/ProductDetail/Torex-Semiconductor/XC6220A331MR-G?qs=AsjdqWjXhJ8ZSWznL1J0gg%3D%3D

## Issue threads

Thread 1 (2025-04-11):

[README] Suprapunere legaturi pe diagrama bloc

marinaoprea, 2025-04-11:
- In diagrama bloc legaturile dintre componente se suprapun intre ele si cu celelalte elemente, facand schema greu de descifrat.

- O amplasare care sa mentina claritatea diagramei ajuta la interpretarea precisa a schemei si a dependintelor dintre componente.

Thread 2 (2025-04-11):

[Images] Lipsa poze cu spatele pcb-ului

marinaoprea, 2025-04-11:
- In folder-ul de Images exista poze doar cu vizualizarea de sus si din lateral a pcb-ului.

- Vizualizarea din spate a pcb-ului poate contribui la prezentarea produsului.

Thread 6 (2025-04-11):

[PCB] Lipsa plan de masa

marinaoprea, 2025-04-11:
- Un plan de masă pe PCB oferă un traseu continuu și uniform pentru semnalele de retur, reduce interferențele electromagnetice, stabilizează potențialul circuitului și contribuie la disiparea căldurii generate de componente.

- Sugestie: utilizeaza plan de masa atat pe layer-ul de top cat si pe layer-ul de bottom.

Closed 2025-04-15.

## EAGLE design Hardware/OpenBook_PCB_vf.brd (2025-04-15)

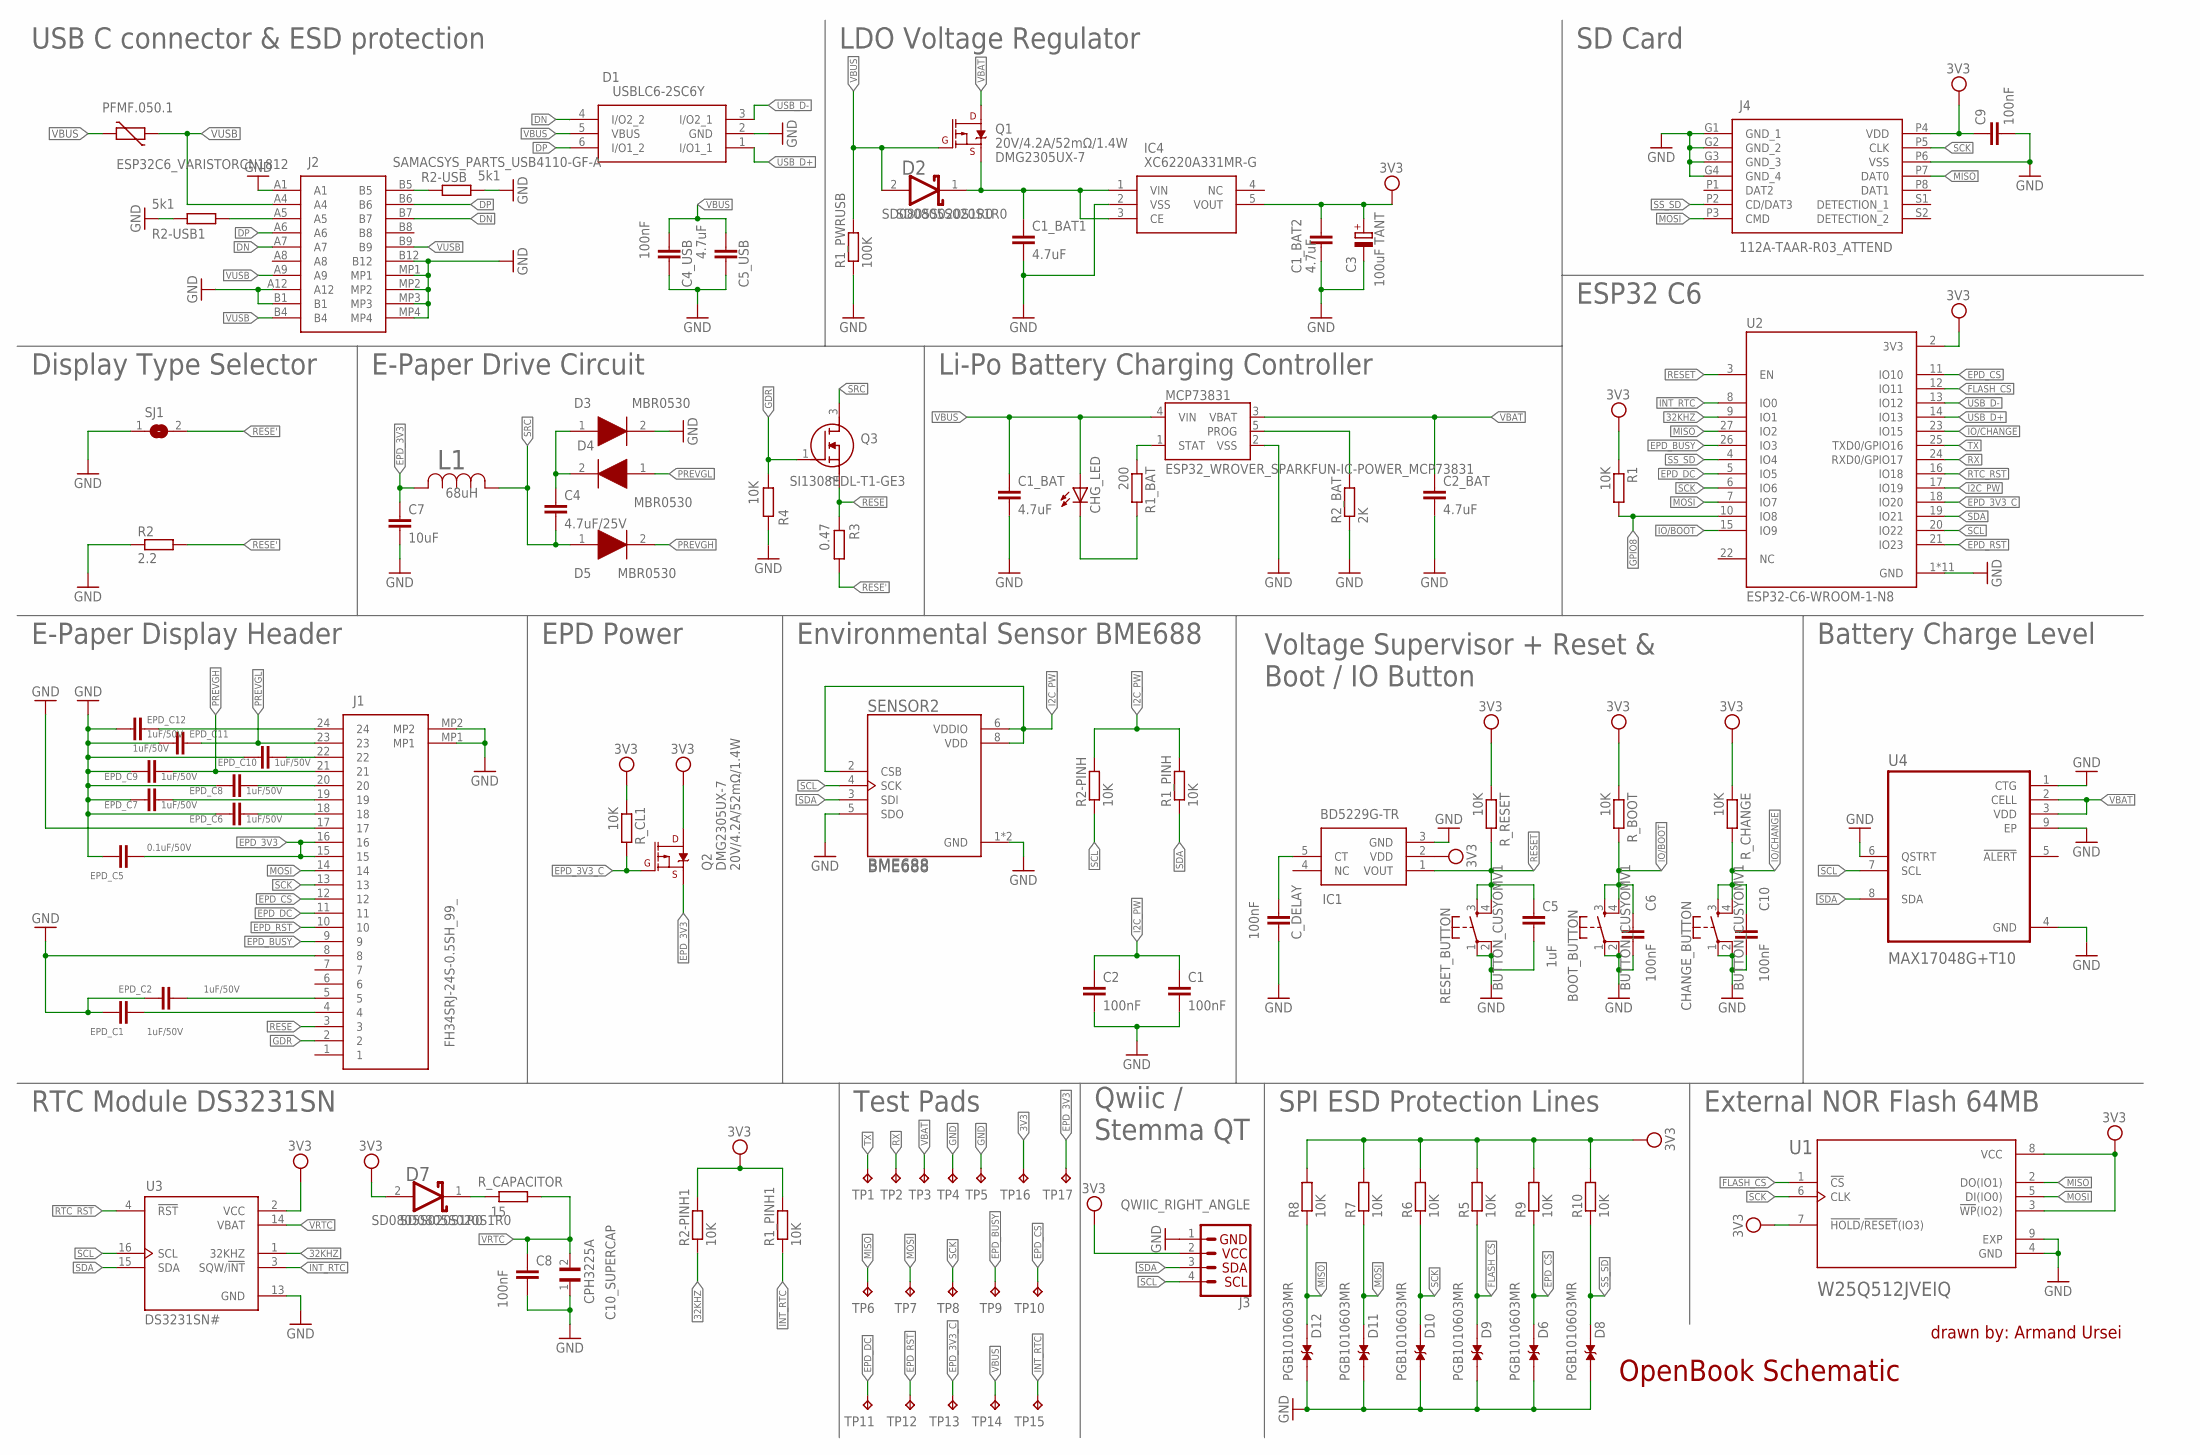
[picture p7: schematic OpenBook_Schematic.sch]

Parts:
BOOT_BUTTON: BUTTON_CUSYOMV1; MYBUTTON
C1, C2, C4_USB, C6, C8, C9, C10: 100nF; ESP32_WROVER_EAGLE-LTSPICE_C0402
C1_BAT, C1_BAT1, C1_BAT2, C2_BAT, C5_USB: 4.7uF; ESP32_WROVER_EAGLE-LTSPICE_C0402
C3: 100uF TANT; RCL_CT3528
C4: 4.7uF/25V; ESP32_WROVER_EAGLE-LTSPICE_C0402
C5: 1uF; ESP32_WROVER_EAGLE-LTSPICE_C0402
C7: 10uF; ESP32_WROVER_EAGLE-LTSPICE_C0402
C10_SUPERCAP: CPH3225A; CAPCP3225X100N
CHANGE_BUTTON: BUTTON_CUSYOMV1; MYBUTTON
CHG_LED: ADAFRUIT_LEDCHIP-LED0603; ADAFRUIT_CHIP-LED0603
C_DELAY: 100nF; ESP32_WROVER_EAGLE-LTSPICE_C0402
D1: USBLC6-2SC6Y; SOT95P280X145-6N
D2, D7: SD0805S020S1R0; ESP32_WROVER_AVX---SD0805S020S1R0_AVX_SD0805S020S1R0_0
D3, D4, D5: MBR0530; SOD3716X135N
D6, D8, D9, D10, D11, D12: PGB1010603MR; DIOC1608X36N
EPD_C1, EPD_C2, EPD_C6, EPD_C7, EPD_C8, EPD_C9, EPD_C10, EPD_C11, EPD_C12: 1uF/50V; ESP32_WROVER_EAGLE-LTSPICE_C0402
EPD_C5: 0.1uF/50V; ESP32_WROVER_EAGLE-LTSPICE_C0402
IC1: BD5229G-TR; SOT95P280X125-5N
IC4: XC6220A331MR-G; SOT95P280X120-5N
J1: FH34SRJ-24S-0.5SH_99_; FH34SRJ24S05SH99
J2: SAMACSYS_PARTS_USB4110-GF-A; SAMACSYS_PARTS_USB4110GFA
J3: QWIIC_RIGHT_ANGLE; JST04_1MM_RA
J4: 112A-TAAR-R03_ATTEND; 112ATAARR03ATTEND
L1: 68uH; IND_4828-WE-TPC_WRE
MCP73831: ESP32_WROVER_SPARKFUN-IC-POWER_MCP73831; ESP32_WROVER_SPARKFUN-IC-POWER_SOT23-5
PFMF.050.1: ESP32C6_VARISTORCN1812; ESP32C6_VARISTOR_CT/CN1812
Q1, Q2: 20V/4.2A/52mΩ/1.4W; ESP32_WROVER_SPARKFUN-DISCRETESEMI_SOT23-3
Q3: SI1308EDL-T1-GE3; SOT65P210X110-3N
R1, R1_PINH, R1_PINH1, R2-PINH, R2-PINH1, R4, R5, R6, R7, R8, R9, R10: 10K; ESP32_WROVER_EAGLE-LTSPICE_R0402
R1_BAT: 200; ESP32_WROVER_EAGLE-LTSPICE_R0402
R1_PWRUSB: 100K; ESP32_WROVER_EAGLE-LTSPICE_R0402
R2: 2.2; ESP32_WROVER_EAGLE-LTSPICE_R0402
R2-USB, R2-USB1: 5k1; ESP32_WROVER_EAGLE-LTSPICE_R0402
R2_BAT: 2K; ESP32_WROVER_EAGLE-LTSPICE_R0402
R3: 0.47; ESP32_WROVER_EAGLE-LTSPICE_R0402
RESET_BUTTON: BUTTON_CUSYOMV1; MYBUTTON
R_BOOT: 10K; ESP32_WROVER_EAGLE-LTSPICE_R0402
R_CAPACITOR: 15; ESP32_WROVER_EAGLE-LTSPICE_R0402
R_CHANGE: 10K; ESP32_WROVER_EAGLE-LTSPICE_R0402
R_CL1: 10K; ESP32_WROVER_EAGLE-LTSPICE_R0402
R_RESET: 10K; ESP32_WROVER_EAGLE-LTSPICE_R0402
SENSOR2: BME688; ESP32_WROVER_BME680_PSON80P300X300X100-8N
SJ1: SJ
TP1, TP2, TP3, TP4, TP5, TP6, TP7, TP8, TP9, TP10, TP11, TP12, TP13, TP14, TP15, TP16, TP17: TPTP20R; TP20R
U1: W25Q512JVEIQ; SON127P600X800X80-9N
U2: ESP32-C6-WROOM-1-N8; XCVR_ESP32-C6-WROOM-1-N8
U3: DS3231SN#; SOIC127P1032X265-16N
U4: MAX17048G+T10; SON50P200X200X80-9N

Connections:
3V3: C1_BAT2.1, C3.+, C9.1, D7.2 (ANODE), IC1.2 (VDD), IC4.5 (VOUT), J3.2, J4.P4 (VDD), Q2.3 (D), R1.1, R1_PINH1.2, R2-PINH1.2, R5.2, R6.2, R7.2, R8.2, R9.2, R10.2, R_BOOT.1, R_CHANGE.1, R_CL1.1, R_RESET.1, TP16.TP, U1.3 (!WP!(IO2)), U1.7 (!HOLD!/!RESET!(IO3)), U1.8 (VCC), U2.2 (3V3), U3.2 (VCC)
32KHZ: R2-PINH1.1, U2.9 (IO1), U3.1 (32KHZ)
DN: D1.4 (I/O2_2), J2.A7, J2.B7
DP: D1.6 (I/O1_2), J2.A6, J2.B6
EPD_3V3: C7.1, EPD_C5.1, J1.15, J1.16, L1.2, Q2.2 (S), TP17.TP
EPD_3V3_C: Q2.1 (G), R_CL1.2, TP13.TP, U2.18 (IO20)
EPD_BUSY: J1.9, TP9.TP, U2.26 (IO3)
EPD_CS: D6.2, J1.12, R9.1, TP10.TP, U2.11 (IO10)
EPD_DC: J1.11, TP11.TP, U2.5 (IO5)
EPD_RST: J1.10, TP12.TP, U2.21 (IO23)
FLASH_CS: D9.2, R5.1, U1.1 (!CS), U2.12 (IO11)
GDR: J1.2, Q3.1 (G), R4.1
GND: BOOT_BUTTON.1, BOOT_BUTTON.2, C1.2, C1_BAT.2, C1_BAT1.2, C1_BAT2.2, C2.2, C2_BAT.2, C3.-, C4_USB.2, C5.2, C5_USB.2, C6.2, C7.2, C8.2, C9.2, C10.2, C10_SUPERCAP.1, CHANGE_BUTTON.1, CHANGE_BUTTON.2, C_DELAY.2, D1.2 (GND), D3.2 (K), D6.1, D8.1, D9.1, D10.1, D11.1, D12.1, EPD_C1.2, EPD_C2.2, EPD_C5.2, EPD_C6.2, EPD_C7.2, EPD_C8.2, EPD_C9.2, EPD_C10.2, EPD_C11.2, EPD_C12.2, IC1.3 (GND), IC4.2 (VSS), J1.8, J1.17, J1.MP1, J1.MP2, J2.A1, J2.A12, J2.B1, J2.B12, J2.MP1, J2.MP2, J2.MP3, J2.MP4, J3.1, J4.G1 (GND_1), J4.G2 (GND_2), J4.G3 (GND_3), J4.G4 (GND_4), J4.P6 (VSS), MCP73831.2 (VSS), R1_PWRUSB.1, R2.1, R2-USB.2, R2-USB1.1, R2_BAT.1, R4.2, RESET_BUTTON.1, RESET_BUTTON.2, SENSOR2.1 (GND), SENSOR2.5 (SDO), SENSOR2.7 (GND), SJ1.1, TP4.TP, TP5.TP, U1.4 (GND), U1.9 (EXP), U2.1 (GND), U2.28 (GND), U2.29_1 (GND), U2.29_2 (GND), U2.29_3 (GND), U2.29_4 (GND), U2.29_5 (GND), U2.29_6 (GND), U2.29_7 (GND), U2.29_8 (GND), U2.29_9 (GND), U3.13 (GND), U4.1 (CTG), U4.4 (GND), U4.6 (QSTRT), U4.9 (EP)
GPIO8: R1.2, U2.10 (IO8)
I2C_PW: C1.1, C2.1, R1_PINH.2, R2-PINH.2, SENSOR2.2 (CSB), SENSOR2.6 (VDDIO), SENSOR2.8 (VDD), U2.17 (IO19)
INT_RTC: R1_PINH1.1, TP15.TP, U2.8 (IO0), U3.3 (SQW/!INT)
IO/BOOT: BOOT_BUTTON.3, BOOT_BUTTON.4, C6.1, R_BOOT.2, U2.15 (IO9)
IO/CHANGE: C10.1, CHANGE_BUTTON.3, CHANGE_BUTTON.4, R_CHANGE.2, U2.23 (IO15)
MISO: D12.2, J4.P7 (DAT0), R8.1, TP6.TP, U1.2 (DO(IO1)), U2.27 (IO2)
MOSI: D11.2, J1.14, J4.P3 (CMD), R7.1, TP7.TP, U1.5 (DI(IO0)), U2.7 (IO7)
unnamed: J2.A5, R2-USB1.2
unnamed: C1_BAT1.1, D2.1 (CATHODE), IC4.1 (VIN), IC4.3 (CE), Q1.2 (S)
unnamed: MCP73831.1 (STAT), R1_BAT.1
unnamed: CHG_LED.C, R1_BAT.2
unnamed: C4.1, D3.1 (A), D4.2 (K)
unnamed: EPD_C12.1, J1.24
unnamed: J2.B5, R2-USB.1
unnamed: MCP73831.5 (PROG), R2_BAT.2
unnamed: EPD_C10.1, J1.22
unnamed: EPD_C8.1, J1.20
unnamed: EPD_C7.1, J1.19
unnamed: EPD_C6.1, J1.18
unnamed: C_DELAY.1, IC1.5 (CT)
unnamed: D7.1 (CATHODE), R_CAPACITOR.2
unnamed: EPD_C2.1, J1.5
unnamed: EPD_C1.1, J1.4
PREVGH: D5.2 (K), EPD_C9.1, J1.21
PREVGL: D4.1 (A), EPD_C11.1, J1.23
RESE: J1.3, Q3.2 (S), R3.1
RESE': R2.2, R3.2, SJ1.2
RESET: C5.1, IC1.1 (VOUT), RESET_BUTTON.3, RESET_BUTTON.4, R_RESET.2, U2.3 (EN)
RTC_RST: U2.16 (IO18), U3.4 (!RST)
RX: TP2.TP, U2.24 (RXD0/GPIO17)
SCK: D10.2, J1.13, J4.P5 (CLK), R6.1, TP8.TP, U1.6 (CLK), U2.6 (IO6)
SCL: J3.4, R2-PINH.1, SENSOR2.4 (SCK), U2.20 (IO22), U3.16 (SCL), U4.7 (SCL)
SDA: J3.3, R1_PINH.1, SENSOR2.3 (SDI), U2.19 (IO21), U3.15 (SDA), U4.8 (SDA)
SRC: C4.2, D5.1 (A), L1.1, Q3.3 (D)
SS_SD: D8.2, J4.P2 (CD/DAT3), R10.1, U2.4 (IO4)
TX: TP1.TP, U2.25 (TXD0/GPIO16)
USB_D+: D1.1 (I/O1_1), U2.14 (IO13)
USB_D-: D1.3 (I/O2_1), U2.13 (IO12)
VBAT: C2_BAT.1, MCP73831.3 (VBAT), Q1.3 (D), TP3.TP, U4.2 (CELL), U4.3 (VDD)
VBUS: C1_BAT.1, C4_USB.1, C5_USB.1, CHG_LED.A, D1.5 (VBUS), D2.2 (ANODE), MCP73831.4 (VIN), PFMF.050.1.2, Q1.1 (G), R1_PWRUSB.2, TP14.TP
VRTC: C8.1, C10_SUPERCAP.2, R_CAPACITOR.1, U3.14 (VBAT)
VUSB: J2.A4, J2.A9, J2.B4, J2.B9, PFMF.050.1.1

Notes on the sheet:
USB C connector & ESD protection
DMG2305UX-7
SD0805S020S1R0
Display Type Selector
LDO Voltage Regulator
SD Card
E-Paper Drive Circuit
Li-Po Battery Charging Controller
ESP32 C6
E-Paper Display Header
EPD Power
BME688
Environmental Sensor BME688
Voltage Supervisor + Reset & Boot / IO Button
Battery Charge Level
RTC Module DS3231SN
Test Pads
Qwiic / Stemma QT
SPI ESD Protection Lines
External NOR Flash 64MB
drawn by: Armand Ursei
OpenBook Schematic

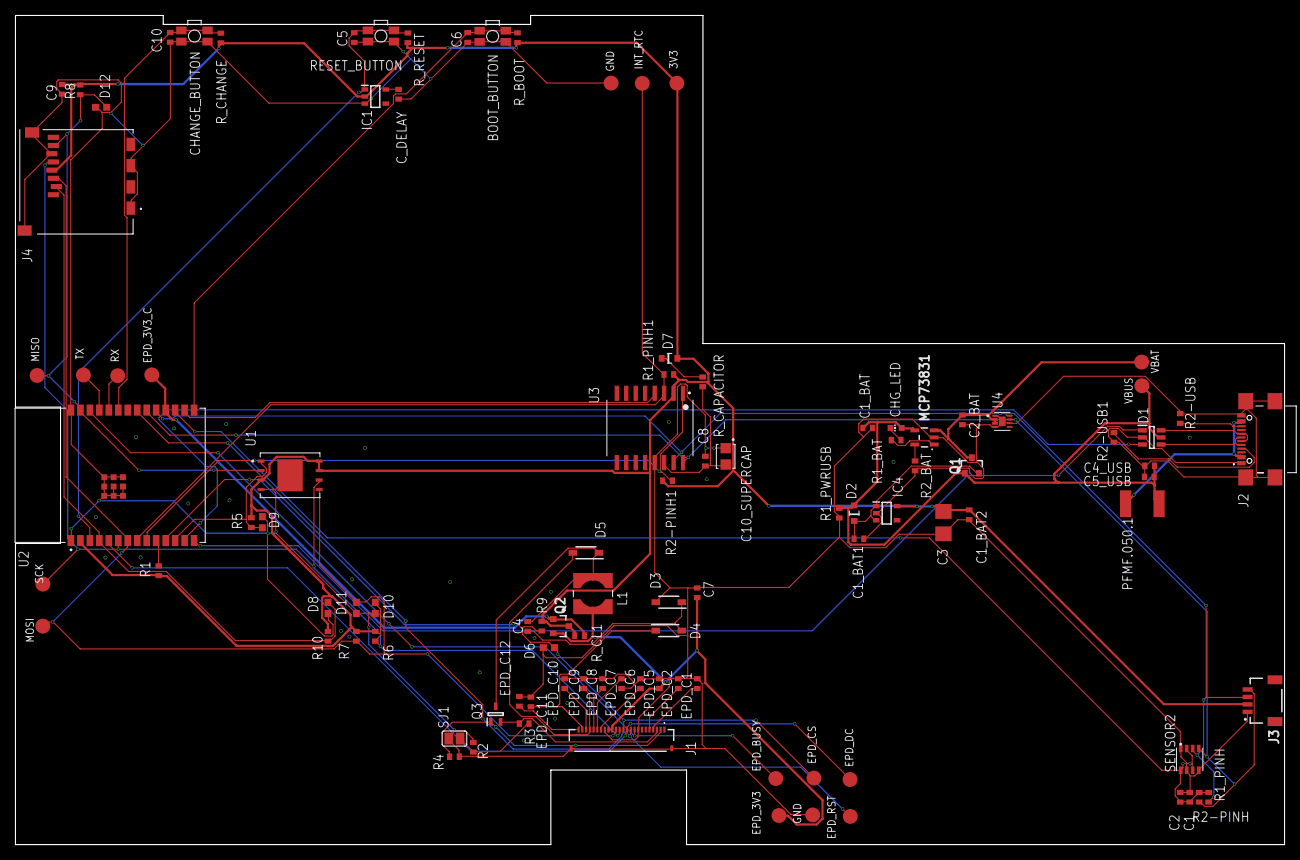
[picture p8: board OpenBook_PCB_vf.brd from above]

Board: 2 copper layers, 170.2 x 111.2 mm, 103 parts (0 on the bottom side), 55 nets.

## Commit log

2025-04-06 +Manufacturing, Images, Mechanical, Hardware files
    [Bill_of_Materials.bom.csv, OpenBook_PCB.brd, OpenBook_Schematic.sch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]
2025-04-06 Update and rename Pick_and_Place.cpl.csv to Pick_and_Place.csv
    [Pick_and_Place.csv]
2026-10-24 Rewrite README in English and tidy repository
    Translate and restructure the documentation, add board specs,
    component table and image gallery, normalize image extensions
    and add a .gitignore for EAGLE/Fusion backups.

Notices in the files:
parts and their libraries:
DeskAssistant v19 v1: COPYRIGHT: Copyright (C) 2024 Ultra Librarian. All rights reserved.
